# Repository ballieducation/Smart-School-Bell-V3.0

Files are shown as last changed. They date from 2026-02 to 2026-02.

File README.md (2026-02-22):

# Industrial STM32 Smart School Bell V3.0


An industrial-grade scheduling solution developed in the **Arduino IDE** for the **STM32F103 (Blue Pill)**. This project replaces outdated manual bells with a high-precision, automated system featuring localized **Punjabi Voice Alerts** and smart timetable generation.
STM32 Smart School Bell V3.0 – Industrial Grade Auto Timetable + Punjabi MP3 Voice Alerts + Multi-Schedule System + Special Exam Mode – Reliable, Crystal-Clear Announcements for Modern Punjabi Schools

## 🚀 Key Features
* **Industrial MCU:** High-performance STM32 core for maximum reliability.
* **Punjabi Voice Alerts:** Professional MP3 announcements for periods, prayers, and breaks.
* **Auto-Timetable Generation:** Input start time and duration; the system builds the schedule automatically.
* **Exam Mode:** Specialized timer with a visual progress bar on an 8x8 LED Matrix.
* **Multi-Timetable Storage:** Save up to 20 unique schedules in non-volatile I2C EEPROM.
* **Hardware Self-Test:** Built-in diagnostic suite to verify RTC, Relay, I2C, and Audio.

## 🛠 Hardware Components
* **MCU:** STM32F103C8T6 (Blue Pill)
* **Display:** 20x4 LCD (I2C) & 8x8 MAX7219 LED Matrix
* **Audio:** DFPlayer Mini & 5W Speaker
* **Timekeeping:** DS3231 RTC (via STM32RTC Library)
* **Storage:** AT24C32/256 EEPROM
* **Output:** 5V Opto-isolated Relay Module

## 🏗 Enclosure Design
The housing for this system was designed in **Solid Edge 2025 Community Edition** and is optimized for **3D Printing**.
* **Mounting:** Dedicated standoffs for STM32 and modules.
* **Interface:** Front-panel cutouts for 20x4 LCD and 3 tactile navigation buttons.

## 🔌 Connection Map (Pinout)
| Component | Pin | Function |
| :--- | :--- | :--- |
| **I2C SDA/SCL** | PB7 / PB6 | LCD & EEPROM |
| **Matrix DIN/CS/CLK**| PA7 / PA4 / PA5 | Visual Indicators |
| **Relay** | PA1 | Bell Control |
| **Buzzer** | PA2 | System Alerts |
| **Buttons** | PB14, PB13, PB12| Set, Up, Down |
| **MP3 RX/TX** | PA10 / PA9 | Audio Communication |

## 📂 Installation & Setup
1. **Arduino IDE:** Install the STM32duino board manager.
2. **Libraries:** Install `STM32RTC`, `LiquidCrystal_I2C`, `LedControl`, and `DFRobotDFPlayerMini`.
3. **SD Card:** Create an `/mp3` folder and upload tracks `0001.mp3` through `0014.mp3`.
4. **Flash:** Upload the `.ino` sketch using an ST-Link V2.

## 📜 Professional Summary
The STM32 Smart School Bell V3.0 provides a professional, high-tech environment for modern educational institutions. It ensures that no period is missed, and every announcement is delivered clearly in the local language, all within a robust, 3D-printed industrial enclosure.

---
Developed by **Balwinder Singh**

Platform: Arduino IDE / STM32duino
Enclosure Design: Solid Edge 2025

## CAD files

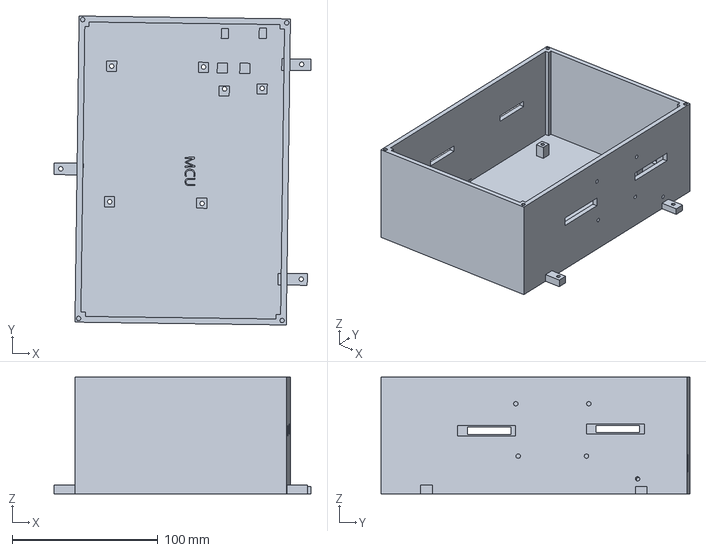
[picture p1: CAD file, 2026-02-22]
Back Panel_Automatic _School Bell.3mf
176.3 x 211.9 x 80.0 mm

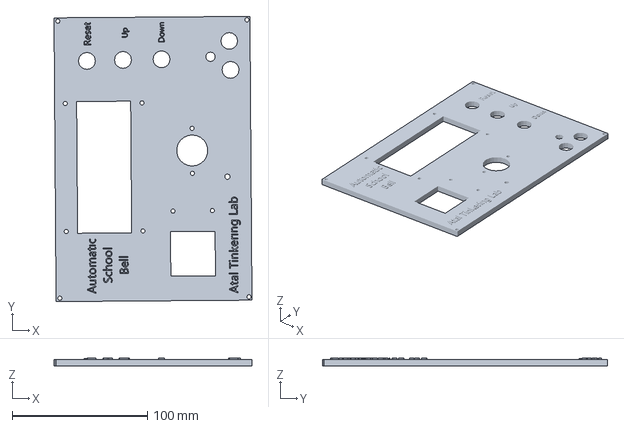
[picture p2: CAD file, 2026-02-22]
Front_Panel_of Automatic School Bell.3mf
146.5 x 211.1 x 5.99 mm

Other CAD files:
Back Panel_Automatic _School Bell.stl
Front_Panel_of Automatic School Bell.stl

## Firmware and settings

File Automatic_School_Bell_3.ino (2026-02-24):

#include <Wire.h>
#include <LiquidCrystal_I2C.h>
#include <LedControl.h>
#include <string.h>
#include <STM32RTC.h>
#include <DFRobotDFPlayerMini.h>

/* ================= BUTTON STRUCT ================= */
struct ButtonState {
  bool last;
  unsigned long lastTime;
};

ButtonState btnSet  = {true, 0};
ButtonState btnUp   = {true, 0};
ButtonState btnDown = {true, 0};

/* ================= HARDWARE ================= */
#define BTN_SET   PB14
#define BTN_UP    PB13
#define BTN_DOWN  PB12

#define EEPROM_ADDR 0x50
#define MAX_BELLS 20
#define TT_NAME_LEN 12
#define EEPROM_BASE 0


#define EEPROM_TTCOUNT_L   0
#define EEPROM_TTCOUNT_H   1
#define EEPROM_DEFAULT_TT  2
#define EEPROM_TT_START    3


/* ---------- 8x8 MAX7219 ---------- */
#define MATRIX_DIN PA7
#define MATRIX_CLK PA5
#define MATRIX_CS  PA4

#define BUZZER_PIN PA2
#define RELAY_PIN  PA1



/* -------- DFPLAYER -------- */
#define MP3_BUSY_PIN PB1
HardwareSerial mp3Serial(PA10, PA9);   // RX, TX

/////////////////////// Start Exam timer //////////////
bool examRunning = false;
bool examScheduled = false;
uint32_t examStartSec = 0;
uint32_t examDurationSec = 0;


//examScheduled = true;


uint8_t examStartH = 0;
uint8_t examStartM = 0;

uint8_t examDurH = 3;   // default 3 hours
uint8_t examDurM = 0;
uint16_t selectedTimetableIndex = 0;

//////////////////////End Exam Timer 
/* ================= UI ================= */
enum UiState {
  UI_DASHBOARD,
  UI_MENU,
  UI_SET_DATETIME,
  UI_SET_BELL,
  UI_MANAGE_Timetable,
  UI_CLEAR_EEPROM,
  UI_TRIGGER_BELL,
  UI_EXAM_TIMER,
  UI_AUTO_BELLS,
  UI_SELFTEST
};

UiState uiState = UI_DASHBOARD;
bool screenChanged = true;


//HardwareSerial &mp3Serial = Serial1;
DFRobotDFPlayerMini mp3;

/* ================= BELL TYPE ================= */
enum BellType : uint8_t
{
  BELL_PERIOD = 0,
  BELL_PRAYER = 1,
  BELL_RECESS = 2,
  BELL_END    = 3
};

LedControl matrix = LedControl(MATRIX_DIN, MATRIX_CLK, MATRIX_CS, 1);
LiquidCrystal_I2C lcd(0x27, 20, 4);

STM32RTC& rtc = STM32RTC::getInstance();

/* ================= DATA ================= */
uint8_t bellCount = 0;
uint8_t bellHour[MAX_BELLS];
uint8_t bellMin[MAX_BELLS];
uint8_t bellType[MAX_BELLS];


bool ttInfoEmbedded = false;
bool bellActive = false;

/* ---- mp3 runtime ---- */
bool mp3Playing = false;
int  activeBellIndex = -1;

/* ================= Time Table  ================= */
void readTimetableName(uint16_t index, char *out)
{
  if (index >= getTimetableCount())
  {
    out[0] = 0;
    return;
  }

  uint16_t addr = getTimetableAddress(index);

  for (uint8_t i = 0; i < TT_NAME_LEN; i++)
    out[i] = eepromReadByte(addr + i);

  out[TT_NAME_LEN] = 0;
}







/* ================= Time Table  ================= */
bool deleteTimetable(uint16_t index)
{
  uint16_t total = getTimetableCount();
  if (total == 0 || index >= total) return false;

  uint16_t addrDel  = getTimetableAddress(index);
  uint16_t addrNext = getTimetableAddress(index + 1);
  uint16_t addrEnd  = getTimetableAddress(total);

  // Shift EEPROM data to close the gap
  for (uint16_t a = addrNext; a < addrEnd; a++)
  {
    uint8_t v = eepromReadByte(a);
    eepromWriteByte(addrDel++, v);
  }

  setTimetableCount(total - 1);

  uint8_t def = getDefaultTimetable();
  if (def == index) 
  {
      setDefaultTimetable(0); // Reset to first if current was deleted
  } 
  else if (def > index) 
  {
      setDefaultTimetable(def - 1); // Shift index down
  }

  // Reload the current default into RAM so the bells update immediately
  loadTimetable(getDefaultTimetable()); 
  
  return true;
}

/* ================= Time Table  ================= */
uint8_t getTimetableBellCount(uint16_t index)
{
  uint16_t addr = getTimetableAddress(index);
  addr += TT_NAME_LEN;
  return eepromReadByte(addr);
}
/* ================= Time Table  ================= */
void readTimetableBell(uint16_t ttIndex,
                        uint8_t bellIndex,
                        uint8_t &h,
                        uint8_t &m,
                        uint8_t &t)
{
  uint16_t addr = getTimetableAddress(ttIndex);

  addr += TT_NAME_LEN;           // skip name
  uint8_t cnt = eepromReadByte(addr++);
  if (bellIndex >= cnt) return;

  addr += bellIndex * 3;

  h = eepromReadByte(addr++);
  m = eepromReadByte(addr++);
  t = eepromReadByte(addr++);
}
/* ================= Time Table  ================= */
void screenTimetableInfo(uint16_t ttIndex)
{
  static uint8_t top = 0;

  if (screenChanged)
  {
    top = 0;
    lcd.clear();
    lcd.noBlink();
    screenChanged = false;
  }

  uint8_t total = getTimetableBellCount(ttIndex);

  char name[TT_NAME_LEN+1];
  readTimetableName(ttIndex, name);

  char line[21];

  // row 0 – name
  snprintf(line, sizeof(line), "TT: %s", name);
  lcdPrintRow(0, line);

  // rows 1 & 2 – two bells per page
  for (uint8_t r = 0; r < 2; r++)
  {
    uint8_t i = top + r;

    if (i < total)
    {
      uint8_t h,m,t;
      readTimetableBell(ttIndex, i, h, m, t);

      char c;
      if      (t == BELL_PERIOD) c = 'C';
      else if (t == BELL_PRAYER) c = 'P';
      else if (t == BELL_RECESS) c = 'R';
      else if (t == BELL_END)    c = 'E';
      else                       c = '?';

      snprintf(line, sizeof(line),
               "B%02d %02d:%02d %c",
               i+1, h, m, c);

      lcdPrintRow(1+r, line);
    }
    else
      lcdPrintRow(1+r, "");
  }

  lcdPrintRow(3, "UP/DN SCROLL SET");

  if (readButton(BTN_DOWN, btnDown))
  {
    if (top + 2 < total) top++;
  }

  if (readButton(BTN_UP, btnUp))
  {
    if (top > 0) top--;
  }

  if (readButton(BTN_SET, btnSet))
  {
    uiState = UI_MENU;   // or back to list (see note below)
    screenChanged = true;
  }
}
/* ================= Time Table  ================= */
/* ================= Time Table  ================= */
/* ================= Time Table  ================= */
/* ================= Time Table  ================= */
/* ================= Time Table  ================= */
/* ================= Time Table  ================= */
/* ================= Time Table  ================= */
/* ================= Time Table  ================= */

void eepromWriteBlock(uint16_t addr, const uint8_t *buf, uint16_t len)
{
  for (uint16_t i = 0; i < len; i++)
    eepromWriteByte(addr + i, buf[i]);
}

void eepromReadBlock(uint16_t addr, uint8_t *buf, uint16_t len)
{
  for (uint16_t i = 0; i < len; i++)
    buf[i] = eepromReadByte(addr + i);
}

uint16_t getTimetableCount()
{
  uint16_t v  = eepromReadByte(EEPROM_TTCOUNT_L);
  v |= (uint16_t)eepromReadByte(EEPROM_TTCOUNT_H) << 8;
  return v;
}

void setTimetableCount(uint16_t c)
{
  eepromWriteByte(EEPROM_TTCOUNT_L, c & 0xFF);
  eepromWriteByte(EEPROM_TTCOUNT_H, (c >> 8) & 0xFF);
}

uint8_t getDefaultTimetable()
{
  return eepromReadByte(EEPROM_DEFAULT_TT);
}

void setDefaultTimetable(uint8_t index)
{
  eepromWriteByte(EEPROM_DEFAULT_TT, index);
}



uint16_t getTimetableAddress(uint16_t index)
{
  uint16_t addr = EEPROM_TT_START;

  uint16_t total = getTimetableCount();
  if (index >= total) index = total;

  for (uint16_t i = 0; i < index; i++)
  {
    addr += TT_NAME_LEN;

    uint8_t cnt = eepromReadByte(addr);

    // ---------- HARD SAFETY ----------
    if (cnt > MAX_BELLS)
      cnt = 0;
    // --------------------------------

    addr += 1;
    addr += cnt * 3;
  }

  return addr;
}


const char *monthName(uint8_t m)
{
  static const char *names[] =
  {"JAN","FEB","MAR","APR","MAY","JUN",
   "JUL","AUG","SEP","OCT","NOV","DEC"};

  if (m < 1 || m > 12) return "UNK";
  return names[m-1];
}

uint8_t countMonthTimetables(const char *base)
{
  uint16_t n = getTimetableCount();
  uint8_t cnt = 0;

  for(uint16_t i=0;i<n;i++)
  {
    char name[TT_NAME_LEN+1];

    uint16_t addr = getTimetableAddress(i);

    for(uint8_t j=0;j<TT_NAME_LEN;j++)
      name[j] = eepromReadByte(addr+j);

    name[TT_NAME_LEN] = 0;

    if (strncmp(name, base, 3) == 0)
      cnt++;
  }
  return cnt;
}
void makeAutoTimetableName(char *out)
{
  uint16_t cnt = getTimetableCount();

  // first ever timetable
  if (cnt == 0)
  {
    strcpy(out, "DEFAULT");
    return;
  }

  uint8_t m = rtc.getMonth();
  const char *base = monthName(m);

  uint8_t already = countMonthTimetables(base);

  if (already == 0)
  {
    strcpy(out, base);
  }
  else
  {
    snprintf(out, TT_NAME_LEN+1, "%s_%d", base, already+1);
  }
}

bool saveCurrentTimetable(const char *name)
{
  uint16_t ttCount = getTimetableCount();

  uint16_t addr = getTimetableAddress(ttCount);

  // name
  for (uint8_t i = 0; i < TT_NAME_LEN; i++)
  {
    uint8_t c = 0;
    if (i < strlen(name)) c = name[i];
    eepromWriteByte(addr++, c);
  }

  // bell count
  eepromWriteByte(addr++, bellCount);

  // bells
  for (uint8_t i = 0; i < bellCount; i++)
  {
    eepromWriteByte(addr++, bellHour[i]);
    eepromWriteByte(addr++, bellMin[i]);
    eepromWriteByte(addr++, bellType[i]);
  }

  setTimetableCount(ttCount + 1);

  // only first timetable becomes default
  if (ttCount == 0)
  {
    setDefaultTimetable(0);
  }

  return true;
}






bool loadTimetable(uint16_t index)
{
  if (index >= getTimetableCount())
    return false;

  uint16_t addr = getTimetableAddress(index);

  // skip name
  addr += TT_NAME_LEN;

  uint8_t cnt = eepromReadByte(addr++);

  if (cnt > MAX_BELLS) return false;

  bellCount = cnt;

  for (uint8_t i = 0; i < bellCount; i++)
  {
    bellHour[i] = eepromReadByte(addr++);
    bellMin[i]  = eepromReadByte(addr++);
    bellType[i] = eepromReadByte(addr++);
  }

  return true;
}


/* ================= Time Table  ================= */


/* ================= FONT ================= */
// index mapping
// 0..9  -> digits 0..9
// 10    -> C
// 11    -> R
// 12    -> P
// 13    -> E

const byte font8x8[][8] =
{
/* 0 */
{0x3C,0x66,0x6E,0x76,0x66,0x66,0x3C,0x00},
/* 1 */
{0x18,0x38,0x18,0x18,0x18,0x18,0x3C,0x00},
/* 2 */
{0x3C,0x66,0x06,0x0C,0x18,0x30,0x7E,0x00},
/* 3 */
{0x3C,0x66,0x06,0x1C,0x06,0x66,0x3C,0x00},
/* 4 */
{0x0C,0x1C,0x3C,0x6C,0x7E,0x0C,0x0C,0x00},
/* 5 */
{0x7E,0x60,0x7C,0x06,0x06,0x66,0x3C,0x00},
/* 6 */
{0x1C,0x30,0x60,0x7C,0x66,0x66,0x3C,0x00},
/* 7 */
{0x7E,0x66,0x06,0x0C,0x18,0x18,0x18,0x00},
/* 8 */
{0x3C,0x66,0x66,0x3C,0x66,0x66,0x3C,0x00},
/* 9 */
{0x3C,0x66,0x66,0x3E,0x06,0x0C,0x38,0x00},

/* 10 = C */
{0x3C,0x66,0x60,0x60,0x60,0x66,0x3C,0x00},

/* 11 = R */
{0x7C,0x66,0x66,0x7C,0x6C,0x66,0x66,0x00},

/* 12 = P */
{0x7C,0x66,0x66,0x7C,0x60,0x60,0x60,0x00},

/* 13 = E */
{0x7E,0x60,0x60,0x7C,0x60,0x60,0x7E,0x00}
};


/* ================= MATRIX ================= */
void drawChar8x8(byte index)
{
  matrix.clearDisplay(0);

  for (int row = 0; row < 8; row++)
  {
    // vertical flip
    byte line = font8x8[index][7 - row];

    for (int col = 0; col < 8; col++)
    {
      // horizontal flip
      bool on = line & (1 << col);

      matrix.setLed(0, row, col, on);
    }
  }
}



/* ================= MATRIX ================= */
/* ================= MATRIX ================= */
void showCountdownOnMatrix(long sec)
{
  if (sec < 0) {
    matrix.clearDisplay(0);
    return;
  }

  if (sec > 60) sec = 60;

  int cols = map(sec, 0, 60, 0, 8);

  matrix.clearDisplay(0);

  for (int c = 0; c < cols; c++) {
    for (int r = 0; r < 8; r++) {
      matrix.setLed(0, r, 7 - c, true);
    }
  }
}

/* ================= INDICATOR ================= */
void updateCountdownIndicators(long countdown)
{
  static unsigned long t = 0;
  static bool blink = false;

  if (bellCount == 0 || countdown < 0) {
    matrix.clearDisplay(0);
    return;
  }

  if (countdown <= 10 && countdown >= 1)
  {
    if (millis() - t > 200) {
      t = millis();
      blink = !blink;
    }

    if (blink) showCountdownOnMatrix(countdown);
    else matrix.clearDisplay(0);

    return;
  }

  if (countdown <= 60) {
    showCountdownOnMatrix(countdown);
    return;
  }

  matrix.clearDisplay(0);
}


/* ================= Time Table  ================= */
/* ================= Time Table  ================= */

void screenTimetableList() {
  static enum { L_LIST, L_INFO, L_CONFIRM } layer = L_LIST;
  static uint16_t sel = 0;
  static uint16_t top = 0;
  static uint8_t infoTop = 0;
  static uint8_t operation = 0; // 1=Delete, 2=Default
  static bool waitRelease = false;

  uint16_t total = getTimetableCount();

  // 1. Safety: Wait for button release
  if (waitRelease) {
    if (digitalRead(BTN_SET) == HIGH && digitalRead(BTN_UP) == HIGH && digitalRead(BTN_DOWN) == HIGH) {
      waitRelease = false;
    }
    return; 
  }

  // 2. Screen Reset
  if (screenChanged) {
    layer = L_LIST; sel = 0; top = 0;
    lcd.clear(); lcd.noBlink();
    screenChanged = false;
  }

  // 3. If EEPROM is empty
  if (total == 0) {
    lcdPrintRow(0, "NO TIMETABLES");
    lcdPrintRow(3, "SET = BACK");
    if (readButton(BTN_SET, btnSet)) { uiState = UI_MENU; screenChanged = true; }
    return;
  }

  char name[TT_NAME_LEN + 1];
  readTimetableName(sel, name);

  /* ================= LAYER: CONFIRMATION (YES/NO) ================= */
  if (layer == L_CONFIRM) {
    lcdPrintRow(0, (operation == 1) ? "DELETE TABLE?" : "SET AS DEFAULT?");
    lcdPrintRow(1, name);
    lcdPrintRow(3, "SET=YES   UP=NO");

    if (readButton(BTN_UP, btnUp)) { // User chose NO
      layer = L_INFO; 
      lcd.clear();
    }
    if (readButton(BTN_SET, btnSet)) { // User chose YES
      if (operation == 1) {
        deleteTimetable(sel);
        total = getTimetableCount();
        if (sel >= total && total > 0) sel = total - 1;
        layer = L_LIST;
      } else {
        setDefaultTimetable(sel);
        loadTimetable(sel);
        layer = L_INFO;
      }
      waitRelease = true; 
      lcd.clear();
    }
    return;
  }

  /* ================= LAYER: DETAIL INFO (Bell List) ================= */
  if (layer == L_INFO) {
    uint8_t bellTotal = getTimetableBellCount(sel);
    lcdPrintRow(0, name);

    for (uint8_t r = 0; r < 2; r++) {
      uint8_t i = infoTop + r;
      if (i < bellTotal) {
        uint8_t h, m, t; readTimetableBell(sel, i, h, m, t);
        
        // Convert Type Number to Text
        const char* typeText = "PERIOD";
        if (t == 1) typeText = "PRAYER";
        else if (t == 2) typeText = "RECESS";
        else if (t == 3) typeText = "END";

        char line[21]; 
        snprintf(line, sizeof(line), "%02d:%02d %s", h, m, typeText);
        lcdPrintRow(r + 1, line);
      } else lcdPrintRow(r + 1, "");
    }
    lcdPrintRow(3, "UP/DN=SCR SET=BACK");

    if (readButton(BTN_DOWN, btnDown) && infoTop + 1 < bellTotal) infoTop++;
    if (readButton(BTN_UP, btnUp) && infoTop > 0) infoTop--;

    // COMBOS for Delete/Default
    if (digitalRead(BTN_SET) == LOW) {
      if (digitalRead(BTN_UP) == LOW)   { operation = 2; layer = L_CONFIRM; waitRelease = true; lcd.clear(); return; }
      if (digitalRead(BTN_DOWN) == LOW) { operation = 1; layer = L_CONFIRM; waitRelease = true; lcd.clear(); return; }
    }

    if (readButton(BTN_SET, btnSet)) { layer = L_LIST; infoTop = 0; lcd.clear(); }
    return;
  }

  /* ================= LAYER: LIST VIEW (Main Selection) ================= */
  if (readButton(BTN_DOWN, btnDown) && sel + 1 < total) sel++;
  if (readButton(BTN_UP, btnUp)) {
    if (sel > 0) sel--;
    else { // If user presses UP at the top of the list, go back to Menu
       uiState = UI_MENU;
       screenChanged = true;
       return;
    }
  }

  if (sel < top) top = sel;
  if (sel >= top + 2) top = sel - 1;

  lcdPrintRow(0, "   SELECT TABLE");
  uint8_t defIdx = getDefaultTimetable();

  for (uint8_t r = 0; r < 2; r++) {
    uint16_t idx = top + r;
    if (idx < total) {
      char tName[TT_NAME_LEN + 1]; readTimetableName(idx, tName);
      char line[21];
      snprintf(line, sizeof(line), "%c %-12s %c", (idx == sel) ? '>' : ' ', tName, (idx == defIdx) ? '*' : ' ');
      lcdPrintRow(r + 1, line);
    } else lcdPrintRow(r + 1, "");
  }
  lcdPrintRow(3, "SET=OPEN  UP=EXIT");

  if (readButton(BTN_SET, btnSet)) { layer = L_INFO; lcd.clear(); }
}



/* ================= Time Table  ================= */
/* ================= Time Table  ================= */










///////////////////////
////////////////////////
/////////////////////////



/* ================= Time Table  ================= */
/* ================= EEPROM ================= */
void eepromWriteByte(uint16_t addr, uint8_t data) {
  Wire.beginTransmission(EEPROM_ADDR);
  Wire.write((uint8_t)(addr >> 8));
  Wire.write((uint8_t)(addr & 0xFF));
  Wire.write(data);
  Wire.endTransmission();
  delay(10);
}

uint8_t eepromReadByte(uint16_t addr) {
  Wire.beginTransmission(EEPROM_ADDR);
  Wire.write(addr >> 8);
  Wire.write(addr & 0xFF);
  Wire.endTransmission();
  Wire.requestFrom(EEPROM_ADDR, (uint8_t)1);
  return Wire.available() ? Wire.read() : 0;
}
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
void loop()
{
  int cb, nb;
  long cd;

  getBellStatus(cb, nb, cd);

  /* =====================================================
     1️⃣  EXACT TIME TRIGGER (ONLY ONCE PER MINUTE)
     ===================================================== */

  static int lastBellMinute = -1;

  int nowH = rtc.getHours();
  int nowM = rtc.getMinutes();
  int nowS = rtc.getSeconds();

  int currentMinute = nowH * 60 + nowM;

  if (!examRunning)
  {
    // Trigger only at second 0 and only once per minute
    if (nowS == 0 && currentMinute != lastBellMinute)
    {
      for (int i = 0; i < bellCount; i++)
      {
        if (bellHour[i] == nowH &&
            bellMin[i]  == nowM)
        {
          activeBellIndex = i;
          bellActive = true;
          mp3Playing = true;

          digitalWrite(BUZZER_PIN, HIGH);
          digitalWrite(RELAY_PIN, LOW);

          break;
        }
      }

      lastBellMinute = currentMinute;
    }
  }

  /* =====================================================
     2️⃣ MATRIX DISPLAY
     ===================================================== */
/* -------- MATRIX DISPLAY -------- */

if (!examRunning)
{
    // Show current bell if valid
    if (cb >= 0 && !(cb == bellCount - 1 && nb == -1 && !bellActive))
    {
        uint8_t t = bellType[cb];

        // 🔹 PRAYER
        if (t == BELL_PRAYER)
        {
            drawChar8x8(12);   // P
        }

        // 🔹 RECESS
        else if (t == BELL_RECESS)
        {
            drawChar8x8(11);   // R
        }

        // 🔹 END
        else if (t == BELL_END)
        {
            // Show only while ringing
            if (bellActive)
                drawChar8x8(13);   // E
            else
                matrix.clearDisplay(0);
        }

        // 🔹 PERIOD
        else if (t == BELL_PERIOD)
        {
            int periodNumber = 0;

            for (int i = 0; i <= cb; i++)
                if (bellType[i] == BELL_PERIOD)
                    periodNumber++;

            if (periodNumber < 10)
                drawChar8x8(periodNumber);
            else
                drawTwoDigitScroll(periodNumber / 10,
                                   periodNumber % 10);
        }
    }
    else
    {
        // Show countdown when no active bell
        updateCountdownIndicators(cd);
    }
}
else
{
    // -------- EXAM MODE MATRIX --------
    uint32_t now = rtcToSeconds();

    if (now >= examStartSec)
    {
        uint32_t elapsed = now - examStartSec;

        if (elapsed < examDurationSec)
            showCountdownOnMatrix(examDurationSec - elapsed);
        else
            matrix.clearDisplay(0);
    }
    else
    {
        matrix.clearDisplay(0);
    }
}



  

  /* =====================================================
     3️⃣ BELL DURATION HANDLER
     ===================================================== */

  if (!examRunning)
    handleBell();

  /* =====================================================
     4️⃣ MP3 CONTROL
     ===================================================== */

/* -------- MP3 CONTROL -------- */

if (mp3Playing)
{
    if (activeBellIndex >= 0)
    {
        uint8_t t = bellType[activeBellIndex];
        uint16_t track = 0;

        // 🔹 PRAYER
        if (t == BELL_PRAYER)
        {
            track = 11;   // 0011.mp3
        }

        // 🔹 RECESS
        else if (t == BELL_RECESS)
        {
            track = 12;   // 0012.mp3
        }

        // 🔹 END
        else if (t == BELL_END)
        {
            track = 13;   // 0013.mp3
        }

        // 🔹 PERIOD
        else if (t == BELL_PERIOD)
        {
            int periodNumber = 0;

            // Count only period bells up to this index
            for (int i = 0; i <= activeBellIndex; i++)
            {
                if (bellType[i] == BELL_PERIOD)
                    periodNumber++;
            }

            // Safety limit (1 to 10)
            if (periodNumber >= 1 && periodNumber <= 10)
                track = periodNumber;
        }

        // 🔥 Play only if track valid
        if (track > 0)
        {
              mp3.play(track);
                       
        }
    }

    mp3Playing = false;
}


  /* =====================================================
     5️⃣ UI HANDLER
     ===================================================== */

  switch (uiState)
  {
    case UI_DASHBOARD:    screenDashboard(); break;
    case UI_MENU:         screenMenu(); break;
    case UI_SET_DATETIME: screenSetDateTime(); break;
    case UI_SET_BELL:     screenSetBell(); break;
    case UI_MANAGE_Timetable: screenTimetableList(); break;
    case UI_CLEAR_EEPROM: screenClearEEPROM(); break;
    case UI_TRIGGER_BELL: screenTriggerBell(); break;
    case UI_EXAM_TIMER:   screenExamTimer(); break;
    case UI_AUTO_BELLS:   screenAutoGenerateBells(); break;
    case UI_SELFTEST:     screenSelfTest(); break;
  }

  delay(80);
}

/* ================= LOOP ================= */
